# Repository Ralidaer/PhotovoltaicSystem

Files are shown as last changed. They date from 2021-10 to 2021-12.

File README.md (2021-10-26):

# PhotovoltaicSystem

WORK IN PROGRESS

Engineering work entitled "A solar system following the sun"
This is a repository for files associated with my engineering work. This repository contain arduino program, photos and word document.
<p>
Demonstration of action (timelapse):

https://user-images.githubusercontent.com/92920833/138950048-f2738cb1-5066-4342-91d9-b7f5de5a17e9.mp4

Subsequent stages of construction:
<p>

<p>

<p>

<p>
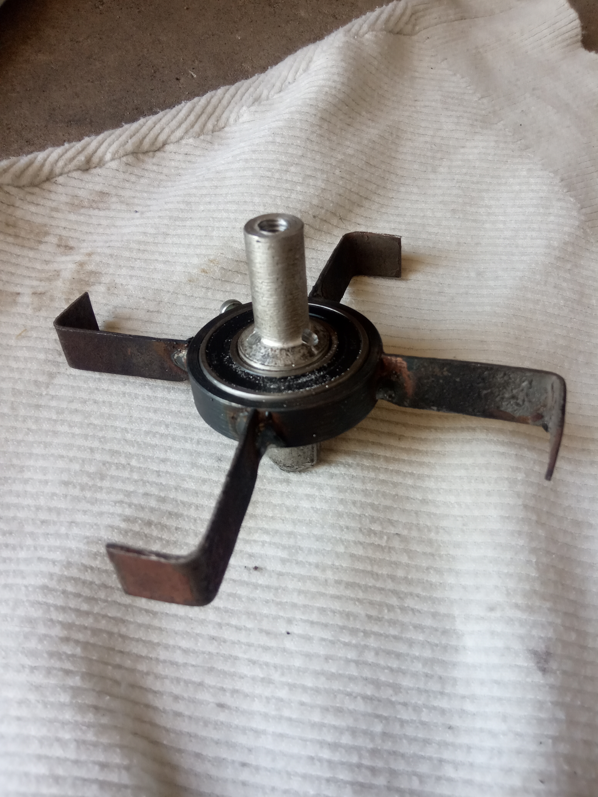
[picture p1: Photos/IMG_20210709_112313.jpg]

<p>
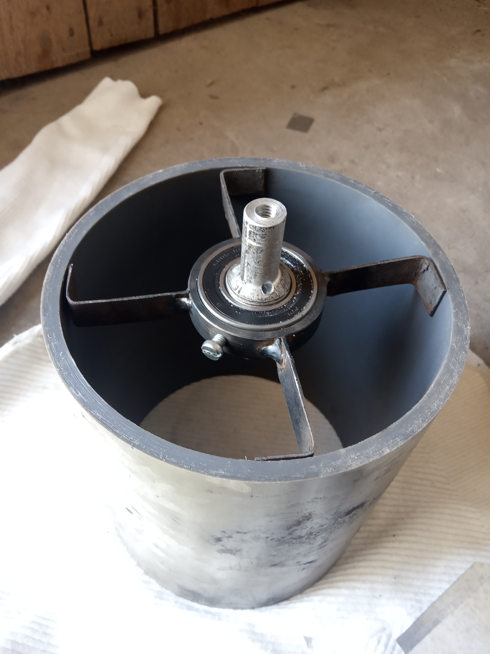
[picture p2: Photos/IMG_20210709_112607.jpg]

<p>
  
<p>
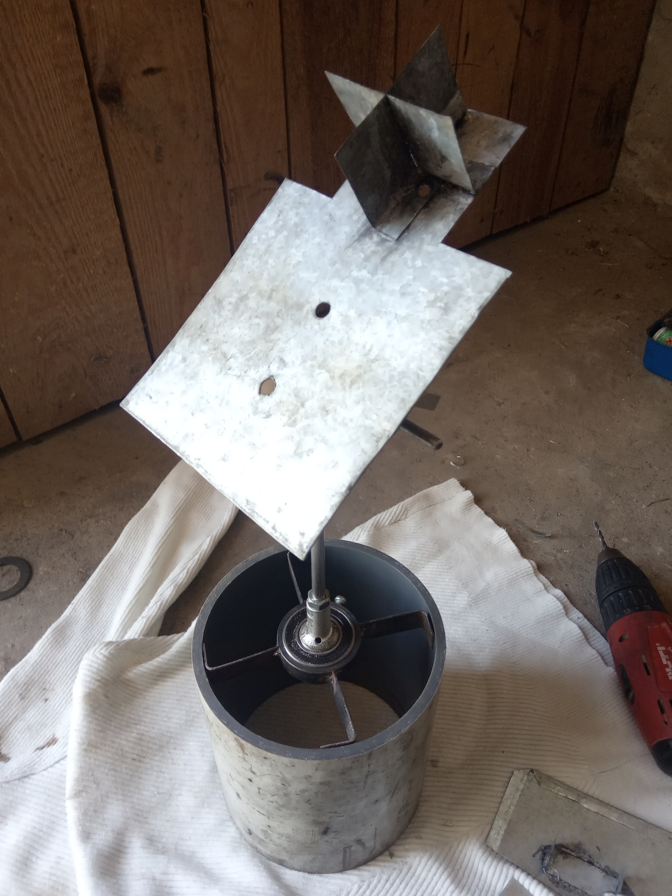
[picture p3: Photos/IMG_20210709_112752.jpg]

<p>
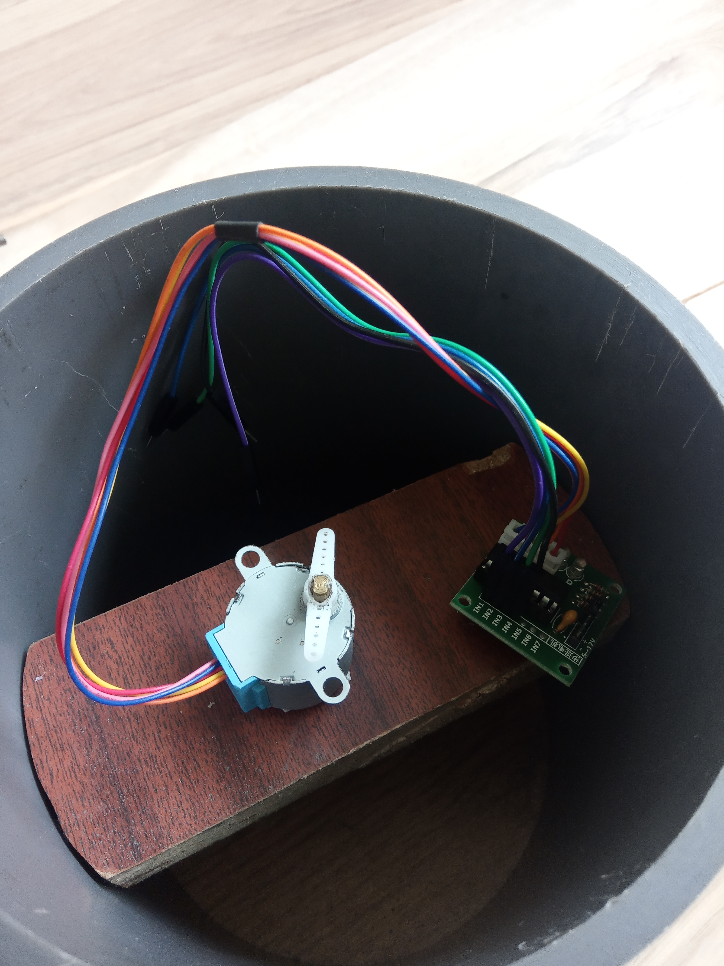
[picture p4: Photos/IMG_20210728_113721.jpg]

<p>


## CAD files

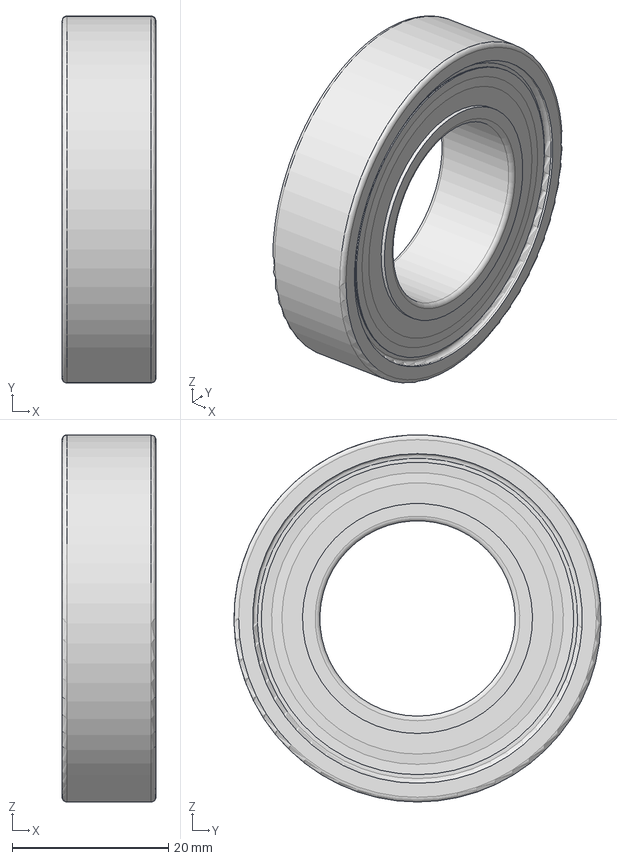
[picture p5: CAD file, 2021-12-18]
CAD/SKF_CAD_MODEL_SKF_6005-2RSH/SKF_6005-2RSH.stp
12.0 x 47.0 x 47.0 mm
_SKF_6005-2RSH_PART1
_SKF_6005-2RSH_PART2
_SKF_6005-2RSH_PART3 x 10
_SKF_6005-2RSH_PART4 x 10

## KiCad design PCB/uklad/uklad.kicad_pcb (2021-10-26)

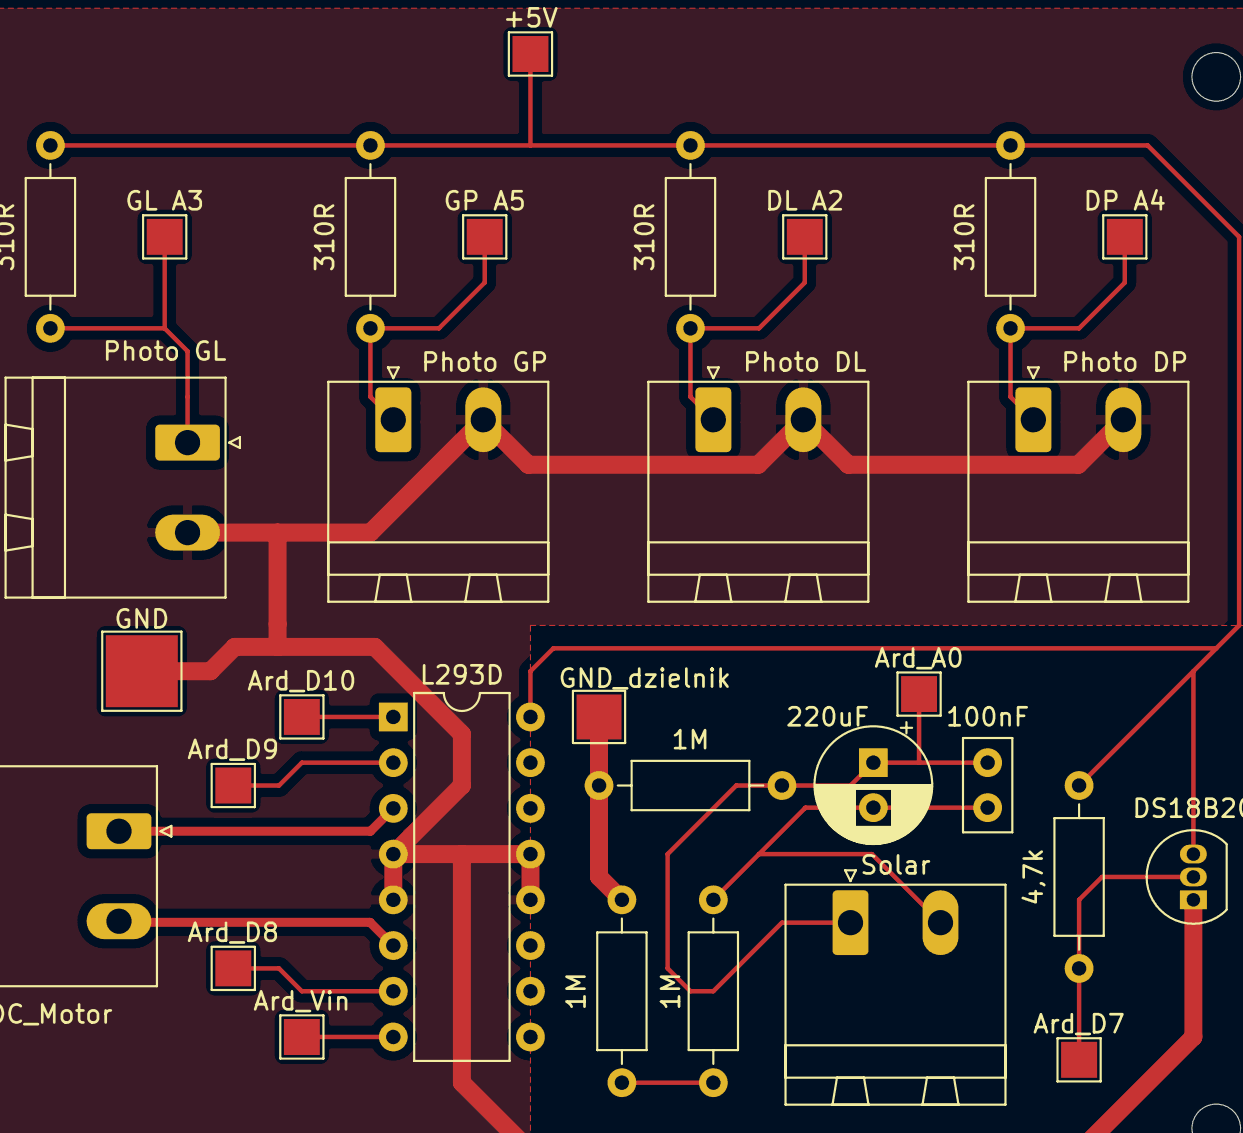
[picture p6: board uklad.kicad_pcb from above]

Board: 2 copper layers, 31 parts (0 on the bottom side), 12 nets.

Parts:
1M, 1M#2, 1M#3: 1M; R_Axial_DIN0207_L6.3mm_D2.5mm_P10.16mm_Horizontal
4,7k: 4,7k; R_Axial_DIN0207_L6.3mm_D2.5mm_P10.16mm_Horizontal
100nF: 100nF; C_Disc_D5.0mm_W2.5mm_P2.50mm
220uF: 220uF; CP_Radial_D6.3mm_P2.50mm
310R, 310R#2, 310R#3, 310R#4: 310R; R_Axial_DIN0207_L6.3mm_D2.5mm_P10.16mm_Horizontal
+5V: TestPoint_Pad_2.0x2.0mm
Ard_A0: TestPoint_Pad_2.0x2.0mm
Ard_D7, Ard_D8, Ard_D9, Ard_D10: TestPoint_Pad_2.0x2.0mm
Ard_Vin: TestPoint_Pad_2.0x2.0mm
DC_Motor: Motor_DC; PhoenixContact_MSTBA_2,5_2-G_1x02_P5.00mm_Horizontal
DL A2: TestPoint_Pad_2.0x2.0mm
DP A4: TestPoint_Pad_2.0x2.0mm
DS18B20: DS18B20; TO-92_Inline
GL A3: TestPoint_Pad_2.0x2.0mm
GND: TestPoint_Pad_4.0x4.0mm
GND_dzielnik: TestPoint_Pad_2.5x2.5mm
GP A5: TestPoint_Pad_2.0x2.0mm
L293D: L293D; DIP-16_W7.62mm
Photo DL: 50-100k; PhoenixContact_MSTBA_2,5_2-G_1x02_P5.00mm_Horizontal
Photo DP: 50-100k; PhoenixContact_MSTBA_2,5_2-G_1x02_P5.00mm_Horizontal
Photo GL: 50-100k; PhoenixContact_MSTBA_2,5_2-G_1x02_P5.00mm_Horizontal
Photo GP: 50-100k; PhoenixContact_MSTBA_2,5_2-G_1x02_P5.00mm_Horizontal
Solar: 9V; PhoenixContact_MSTBA_2,5_2-G_1x02_P5.00mm_Horizontal

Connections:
+5V: 4,7k.1, 310R.1, 310R#2.1, 310R#3.1, 310R#4.1, DS18B20.3, L293D.16
GND: 1M#2.1, 1M#3.2, DS18B20.1, L293D.4, L293D.5, L293D.12, L293D.13, Photo DL.2, Photo DP.2, Photo GL.2, Photo GP.2
unnamed: 310R#4.2, Photo GL.1
unnamed: 310R#3.2, Photo GP.1
unnamed: 310R#2.2, Photo DL.1
unnamed: 310R.2, Photo DP.1
unnamed: 1M#3.1, 100nF.1, 220uF.1, Solar.1
unnamed: 4,7k.2, DS18B20.2
unnamed: 1M.2, 100nF.2, 220uF.2, Solar.2
unnamed: DC_Motor.1, L293D.3
unnamed: DC_Motor.2, L293D.6
unnamed: 1M.1, 1M#2.2

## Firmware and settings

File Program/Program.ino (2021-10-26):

#include <Stepper.h>
#include <OneWire.h>
#include <DallasTemperature.h>
#include <SPI.h>
#include <SD.h>

#define szyna_one_wire 7

float Gora = 0;
float Dol = 0;
float Lewo = 0;
float Prawo = 0;
float Przelicznik = 5.0/1023.0;
float SredniaFoto = 0;
float Dzielnik = 0;
float Panel = 0;
float RoznicaGD = 0;
float RoznicaLP = 0;
float Temperatura = 0;
long Pomiar = 1;

const int krokiNaObrot = 500;

Stepper myStepper(krokiNaObrot, 2, 3, 5, 6);
OneWire oneWire(szyna_one_wire);
DallasTemperature czujnik(&oneWire);
File plikPomiarowy;

void setup(){
  Serial.begin(9600); //Rozpoczęcie transmisji z Serial Monitor'em
  myStepper.setSpeed(10); //Ustawienie szybkości silnika krokowego
  czujnik.begin(); //inicjalizacja szyny One_Wire
  pinMode(10, OUTPUT); //Sygnał PWM silnika wychylającego
  digitalWrite(10, LOW);
  pinMode(9, OUTPUT); //Sygnał 1 sterujący kierunkiem obrotów silnika wychylającego
  digitalWrite(9, LOW);
  pinMode(8, OUTPUT); //Sygnał 2 sterujący kierunkiem obrotów silnika wychylającego
  digitalWrite(8, LOW);
  pinMode(15, INPUT_PULLUP); //Pin A1 jako czujnik wychylenia granicznego (dół)
  //pinMode(0, INPUT_PULLUP); //Pin D0 jako czujnik wychylenia granicznego (góra)

  delay(3000);
  
  Serial.println("Inicjalizacja karty microSD...");
  while(!SD.begin(4)){
    Serial.println("Trwa inicjalizacja...");
    delay(500);
  }
  Serial.println("Inicjalizacja powiodla sie");

  plikPomiarowy = SD.open("pomiar.txt", FILE_WRITE); //otworzenie pliku tekstowego
  if(plikPomiarowy){ //Rozpoczęcie zapisu pomiarów
    Serial.println("Seria pomiarowa: 5");
    plikPomiarowy.println("Seria pomiarowa: 5 (obracanie, wychylanie)");
    Serial.println("Data: 20.10.2021, Godzina poczatkowa: --:--, Godzina koncowa: --:--");
    plikPomiarowy.println("Opis serii pomiarowej: Małe zachmurzenie, obracanie wychylanie");
    plikPomiarowy.println("Data: 20.10.2021, Godzina poczatkowa: --:--, Godzina koncowa: --:--");
    plikPomiarowy.println("Pogoda: ");
    plikPomiarowy.println("Pomiar,Czas w ms, Dzielnik, Panel, Temperatura, SredniaFoto");
    plikPomiarowy.close();
  }else
    Serial.println("Nie udalo sie otworzyc pliku pomiar.txt");
}

void pomiar(){
  Gora = (analogRead(A2)+analogRead(A4))/2*Przelicznik; //średnia wartość spadków napięcia na fotorezystorach górnych
  Dol = (analogRead(A3)+analogRead(A5))/2*Przelicznik; //średnia wartość spadków napięcia na fotorezystorach dolnych
  Lewo = (analogRead(A3)+analogRead(A4))/2*Przelicznik; //średnia wartość spadków napięcia na fotorezystorach prawych
  Prawo = (analogRead(A2)+analogRead(A5))/2*Przelicznik; //średnia wartość spadków napięcia na fotorezystorach lewych
  SredniaFoto = (Gora+Dol+Lewo+Prawo)/4.0; //średnia wartość spadków napięć na wszystkich fotorezystorach
  RoznicaGD=abs(Gora-Dol); //różnica średnich spadków napięć dolnych i górnych
  RoznicaLP=abs(Lewo-Prawo); //różnica średnich spadków napięć lewych i prawych
  Dzielnik = analogRead(A0)*Przelicznik; //spadek napięcia na rezystorze 1M w dzielniku napięcia
  Panel = Dzielnik*3.00; //przeliczenie spadku napięcia Dzielnik na napięcie na panelu fotowoltaicznym
  czujnik.requestTemperatures(); // wysłanie komendy w celu zmierzenia temperatury
  Temperatura=czujnik.getTempCByIndex(0); //odczytanie temperatury
}

void zapis(){
  SD.begin(4);
  delay(50);
  plikPomiarowy = SD.open("pomiar.txt", FILE_WRITE); //otworzenie pliku tekstowego
  delay(50);
  if(plikPomiarowy){
    plikPomiarowy.print(Pomiar);
    plikPomiarowy.print(",");
    plikPomiarowy.print(millis());
    plikPomiarowy.print(",");
    //plikPomiarowy.print(Dzielnik);
    //plikPomiarowy.print(",");
    //plikPomiarowy.print(Panel);
    //plikPomiarowy.print(",");
    plikPomiarowy.print(Temperatura);
    plikPomiarowy.print(",");
    plikPomiarowy.println(SredniaFoto);
    plikPomiarowy.close();
  }else
    Serial.println("Nie udalo sie otworzyc pliku pomiar.txt");
}

void wyswietlenie(){
  Serial.print("Pomiar: ");
  Serial.print(Pomiar); //wyświetlenie numeru Pomiaru od początku działania systemu
  Serial.print("\t");

  Serial.print("Aktualny czas [ms]: ");
  Serial.print(millis()); //wyświetlenie aktualnego czasu w ms
  Serial.print("\t");
  
  Serial.print("Góra: ");
  Serial.print(Gora); //wyświetlenie wartości średniej spadków napięć na fotorezystorach górnych
  Serial.print("\t");
  
  Serial.print("Dół: ");
  Serial.print(Dol); //wyświetlenie wartości średniej spadków napięć na fotorezystorach dolnych
  Serial.print("\t");
   
  Serial.print("Lewo: ");
  Serial.print(Lewo); //wyświetlenie wartości średniej spadków napięć na fotorezystorach lewych
  Serial.print("\t");
   
  Serial.print("Prawo: ");
  Serial.print(Prawo); //wyświetlenie wartości średniej spadków napięć na fotorezystorach prawych
  Serial.print("\t");

  Serial.print("Dzielnik: ");
  Serial.print(Dzielnik); //wyświetlenie wartości spadku napięcia na rezystorze 1M w dzielniku napięcia
  Serial.print("\t");

  Serial.print("Panel: ");
  Serial.print(Panel); //wyświetlenie wartości napięcia na panelu fotowoltaicznym
  Serial.print("\t");

  Serial.print("Temperatura: ");
  Serial.println(Temperatura); //wyświetlenie temperatury panelu fotowoltaicznego
}

void ruch(){
  
  if(RoznicaGD > 0.04){ //sprawdzenie czy występuje różnica między spadkiem napięć na fotorezystorach górnych i dolnych 
    if(Gora>Dol){ //sprawdzenie gdzie jest większa średnia wartość spadków napięcia (góra czy dół)
      if(digitalRead(15) == HIGH){ //Sprawdzenie czy mechanizm śrubowy nie osiągnął położenia skrajnego
        digitalWrite(10, HIGH);
        digitalWrite(9, LOW); 
        digitalWrite(8, HIGH); //Silnik wychylający - obroty w pierwszym kierunku
      }else{
        digitalWrite(10, LOW);
        digitalWrite(9, LOW); 
        digitalWrite(8, LOW);
      }
    }else{
        digitalWrite(10, HIGH); 
        digitalWrite(9, HIGH);
        digitalWrite(8, LOW); //Silnik wychylający - obroty w drugim kierunku
    }
  }else{
    digitalWrite(10, LOW); //Zatrzymanie silnika wychylającego
    digitalWrite(9, LOW); 
    digitalWrite(8, LOW);
  }
  
  
  if(RoznicaLP > 0.03) //sprawdzenie czy występuje różnica między spadkiem napięć na fotorezystorach lewych i prawych
    if(Lewo<Prawo) //sprawdzenie gdzie jest większa średnia wartość spadków napięcia (lewo czy prawo)
      myStepper.step(-10); //ruch silnika krokowego w jednym kierunku
    else
      myStepper.step(10); //ruch silnika krokowego w drugim kierunku
}

void loop(){
  pomiar();
  //delay(50);
  zapis();
  //delay(50);
  wyswietlenie();
  Pomiar=Pomiar+1;
  //delay(50);
  ruch();
  //delay(500);
}

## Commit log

2021-10-26 add videos, photos, docx file and PCB project
    [DanePomiarowe.xlsx, Złożenie.cfg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]
2021-12-18 removing files
    [DanePomiarowe.xlsx, Złożenie.cfg]
2021-12-18 new files
    [SKF_6005-2RSH.cfg, SKF_6005-2RSH.stp, zlozenie.cfg]

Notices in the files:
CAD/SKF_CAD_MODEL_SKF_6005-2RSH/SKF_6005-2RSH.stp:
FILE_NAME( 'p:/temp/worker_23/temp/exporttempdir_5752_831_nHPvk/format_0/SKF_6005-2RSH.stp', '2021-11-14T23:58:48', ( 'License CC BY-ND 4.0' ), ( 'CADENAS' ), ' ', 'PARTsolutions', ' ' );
